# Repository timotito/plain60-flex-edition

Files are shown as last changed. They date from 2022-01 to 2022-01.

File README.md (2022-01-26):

# Plain60 Flex Edition rev2.2.1
This is an independently developed branch of the Plain60 Flex Edition, by evyd13.

Plain60 Flex Edition PCB
This universal 60% PCB is designed to support as little layouts as possible without limiting usability for most users. The reason evyd13 did this is because other PCBs made for this form factor usually have so many supported layouts that it could almost qualify as swiss cheese.

It also features a fuse and an ESD protection chip to protect the MCU and other parts of the PCB.

## Features
- Fits in the TGR Unikorn
- Compatible with QMK Firmware and VIA Configurator (if you flash a VIA compatible .hex file)
- Compatible with most universal 60% cases and HHKB/WKL Tofu by KBDfans
- USB type-C
- Optional JST header for connection with daughterboard
- Footprint for optional speaker (AST1109MLTRQ)
- ESD protection and fuse
- No LEDs and no underglow
- Minimal layout support
- ISP header

## Supported layouts
Supported layouts of the Plain60-C

## Building
If you feel like building a few of these PCBs yourself, the required gerber files are in the named folder. Order those at your favourite PCB manufacturer, get the components needed (see included BOM) and solder them on! Alternatively, request SMT assembly from the manufacturer.

A hot air station is not required but a soldering iron is. Flux is recommended.

## Opening the project
To open the files you will need KiCAD.

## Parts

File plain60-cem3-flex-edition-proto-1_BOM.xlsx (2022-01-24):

LCSC part # | Designator | Type | Value | Package | Amount | Description
C38141 (https://lcsc.com/product-detail/Multilayer-Ceramic-Capacitors-MLCC-SMD-SMT_FH-Guangdong-Fenghua-Advanced-Tech-0805B104K500NT_C38141.html) | 0.1u | Capacitor | 0.1uF | 0805 | 4 | 50V 100nF X7R ±10% 0805 Multilayer Ceramic Capacitors MLCC - SMD/SMT ROHS
C106843 (https://www.lcsc.com/product-detail/Multilayer-Ceramic-Capacitors-MLCC-SMD-SMT_YAGEO-CC0805KKX7R9BB474_C106843.html) | 4.7u | Capacitor | 4.7uF | 0805 | 1 | 50V 470nF X7R ±10% 0805 Multilayer Ceramic Capacitors MLCC - SMD/SMT ROHS
C215803 | 1u | Capacitor | 1uF | 0805 | 1 | 50V 1uF X7R ±10% 0805 Multilayer Ceramic Capacitors MLCC - SMD/SMT ROHS
C109001 | D1, D2, D3, D4, D5, D6, D7, D8, D9, D10, D11, D12, D13, D14, D15, D16, D17, D18, D19, D20, D21, D22, D23, D24, D25, D26, D27, D28, D29, D31, D32, D33, D34, D35, D36, D37, D38, D39, D40, D41, D42, D43, D44, D46, D47, D48, D49, D50, D51, D52, D53, D54, D55, D56, D57, D58, D59, D61, D62, D63, D67, D71, D72, D73, D74 | Diode |  | 0805 | 65 | 75V +150℃@(Tj) 400mW 1.25V@100mA 4ns 5μA@75V 150mA 0805 Switching Diode ROHS
C261942 | F1 | Fuse |  | 0805 | 1 | 6V 500mA 100A 500mW -40℃~+85℃ 1A 100ms 0805 Resettable Fuses ROHS
C165948 | J1 | Connector |  | HRO-TYPE-C-31-M-12 | 1 | 250mA 1 16 Female Type-C SMD USB Connectors ROHS
C103904 | 10k | Resistor | 10K | 0805 | 2 | ±1% 1/8W Thick Film Resistors 150V ±100ppm/℃ -55℃~+155℃ 10kΩ 0805 Chip Resistor - Surface Mount ROHS
C212411 | 5.1k | Resistor | 5.1K | 0805 | 2 | ±1% 1/8W Thick Film Resistors 150V ±100ppm/℃ -55℃~+155℃ 5.1kΩ 0805 Chip Resistor - Surface Mount ROHS
C325772 | 22 | Resistor | 22 | 0805 | 2 | ±1% 0.125W 22Ω 0805 Chip Resistor - Surface Mount ROHS
C44854 | U1 | MCU | 32U4 | QFP-44 | 1 | 16MHz AVR 2.7V ~ 5.5V QFP-44_10x10x08P ATMEL & AVR ROHS
C7519 | U2 | ESD chip |  | SOT23-6 | 1 | 17V 5A 5.25V 6V Unidirectional SOT-23-6 ESD Protection Devices ROHS
C341521 | X1 | Resonator | 16MHz | SMD | 1 | 16MHz ±0.5% 15pF 40Ω SMD3213-3P Ceramic Resonators ROHS
C92584 | SW1 | Switch |  | SMD | 1 | -25℃~+85℃ 5.2mm 1.5mm Round Button 50mA Brick nogging 5.2mm SPST 100MΩ 100000 250gf@±30gf 12V SMD Tactile Switches ROHS
C160404 | UDB | Optional JST |  | SMD | 1 | 1x4P 1 SR/SZ 1mm 4 Copper Alloy - Wire To Board / Wire To Wire Connector ROHS

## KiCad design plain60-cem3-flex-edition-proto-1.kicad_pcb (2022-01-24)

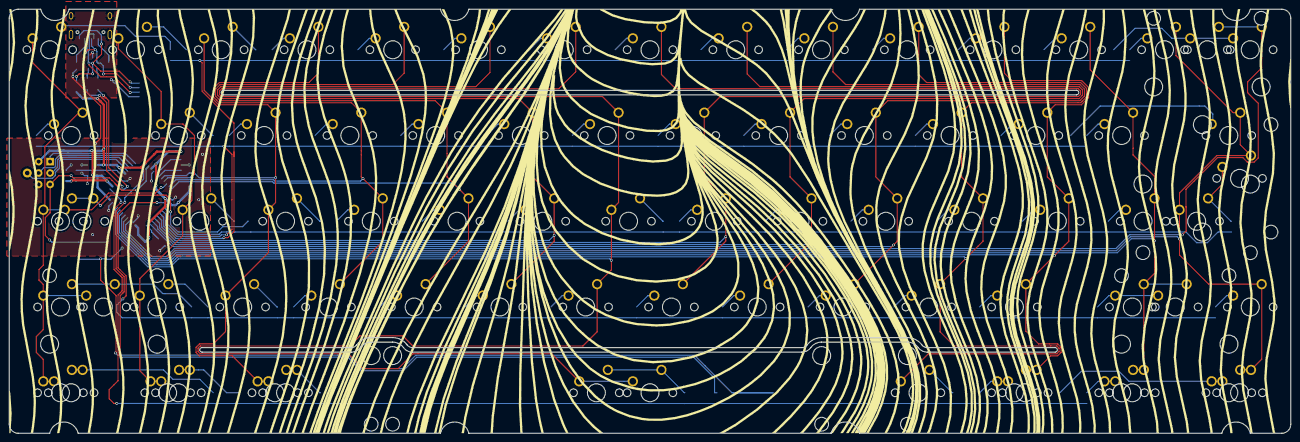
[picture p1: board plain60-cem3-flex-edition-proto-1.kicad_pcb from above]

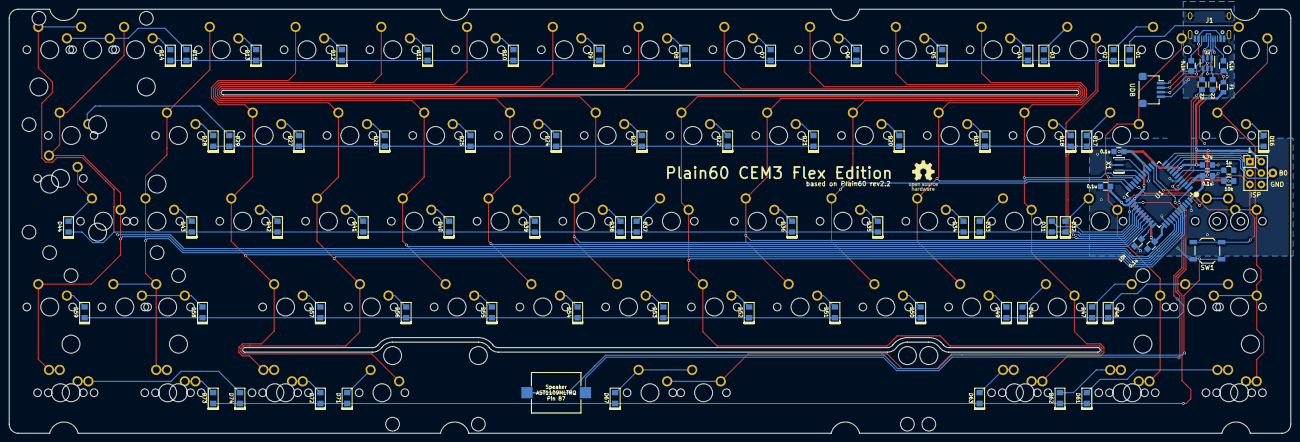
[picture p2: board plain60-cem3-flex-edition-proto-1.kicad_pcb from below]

Board: 2 copper layers, 284.7 x 94.2 mm, 174 parts (87 on the bottom side), 106 nets.

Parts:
C1: 1u; C_0805
C2, C3, C4, C5: 0.1u; C_0805
C6: 4.7u; C_0805
D1: D1; D_0805
D2: D2; D_0805
D3: D3; D_0805
D4: D4; D_0805
D5: D5; D_0805
D6: D6; D_0805
D7: D7; D_0805
D8: D8; D_0805
D9: D9; D_0805
D10: D10; D_0805
D11: D11; D_0805
D12: D12; D_0805
D13: D13; D_0805
D14: D14; D_0805
D15: D15; D_0805
D16: D16; D_0805
D17: D17; D_0805
D18: D18; D_0805
D19: D19; D_0805
D20: D20; D_0805
D21: D21; D_0805
D22: D22; D_0805
D23: D23; D_0805
D24: D24; D_0805
D25: D25; D_0805
D26: D26; D_0805
D27: D27; D_0805
D28: D28; D_0805
D29: D29; D_0805
D31: D31; D_0805
D32: D32; D_0805
D33: D33; D_0805
D34: D34; D_0805
D35: D35; D_0805
D36: D36; D_0805
D37: D37; D_0805
D38: D38; D_0805
D39: D39; D_0805
D40: D40; D_0805
D41: D41; D_0805
D42: D42; D_0805
D43: D43; D_0805
D44: D44; D_0805
D46: D46; D_0805
D47: D47; D_0805
D48: D48; D_0805
D49: D49; D_0805
D50: D50; D_0805
D51: D51; D_0805
D52: D52; D_0805
D53: D53; D_0805
D54: D54; D_0805
D55: D55; D_0805
D56: D56; D_0805
D57: D57; D_0805
D58: D58; D_0805
D59: D59; D_0805
D61: D61; D_0805
D62: D62; D_0805
D63: D63; D_0805
D67: D67; D_0805
D71: D71; D_0805
D72: D72; D_0805
D73: D73; D_0805
D74: D74; D_0805
F1: Polyfuse; R_0805
H1: B0; free_pin
J1: HRO-TYPE-C-31-M-12
J2: ISP; isp_standard
J3: ai03_ud; JST_SH_SM04B-SRSS-TB_1x04-1MP_P1.00mm_Horizontal
K1, K2, K3, K4, K5, K6, K7, K8, K9, K10, K11, K12, K13, K14, K15-1, K17, K18, K19, K20, K21, K22, K23, K24, K25, K26, K27, K28, K32, K33, K34, K35, K36, K37, K38, K39, K40, K41, K42, K43, K47, K48, K49, K50, K51, K52, K53, K54, K55, K56, K57, K59, K62-1, K73-1: KEYSW; CHERRY_PLATE_100H
K15: KEYSW; CHERRY_PCB_200H
K16, K29, K61-1, K63-1, K72-1, K74-1: KEYSW; CHERRY_PLATE_150H
K31, K58-1: KEYSW; CHERRY_PLATE_175H
K31-1, K46-1, K61, K62, K63, K71, K72, K73, K74: KEYSW; CHERRY_PLATE_125H
K44: KEYSW; CHERRY_PCB_225H_F
K44-1: KEYSW; CHERRY_PCB_200H_V
K46: KEYSW; CHERRY_PCB_225H
K58: KEYSW; CHERRY_PCB_275H
K67: KEYSW; CHERRY_PCB_625H_F
K67-1: KEYSW; CHERRY_PCB_700H_F
LS1: Speaker; speaker_AST1109MLTRQ
R1, R2: 22; R_0805
R3, R4: 5.1k; R_0805
R5, R6: 10k; R_0805
Ref**: Val**; redss
S1, S2, S3, S6: Screw; 5.5_5x2.5mm
S4, S5: Screw; 10x5_7x2.5mm
S7, S8, S9: Tofu screw; 5.5_5x2.5mm
SW1: SW_PUSH; SW_SPST_TL3342
U1: ATmega32U4; ATMEGA32U4
U2: USBLC6-2SC6
X1: XTAL_GND; Resonator_SMD_muRata_CSTNExxV-3Pin-p1.2

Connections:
D+: J1.6 (DP1), J1.8 (DP2), J3.3, U2.1 (I/O1)
D-: J1.5 (DN2), J1.7 (DN1), J3.2, U2.3 (I/O2)
GND: C1.2, C2.1, C3.1, C4.1, C5.1, C6.1, J1.1 (GND), J1.12 (GND), J1.13 (SHIELD), J2.6, J3.4, LS1.2, R3.1, R4.2, R6.1, SW1.1, U1.5 (UGND), U1.15 (GND), U1.23 (GND), U1.35 (GND), U1.43 (GND), U2.2 (GND), X1.3
MISO: J2.1, U1.11 ((PDO/MISO/PCINT3)PB3)
MOSI: J2.4, U1.10 ((PDI/MOSI/PCINT2)PB2)
unnamed: C1.1, U1.6 (UCAP)
unnamed: D1.2 (A), K1.1
unnamed: D2.2 (A), K2.1
unnamed: D3.2 (A), K3.1
unnamed: D4.2 (A), K4.2
unnamed: D5.2 (A), K5.2
unnamed: D6.2 (A), K6.2
unnamed: D7.2 (A), K7.2
unnamed: D8.2 (A), K8.2
unnamed: D9.2 (A), K9.2
unnamed: D10.2 (A), K10.2
unnamed: D11.2 (A), K11.2
unnamed: D12.2 (A), K12.2
unnamed: D13.2 (A), K13.2
unnamed: D14.2 (A), K14.2
unnamed: D15.2 (A), K15.2, K15-1.2
unnamed: D16.2 (A), K16.2
unnamed: D17.2 (A), K17.1
unnamed: D18.2 (A), K18.2
unnamed: D19.2 (A), K19.2
unnamed: D20.2 (A), K20.2
unnamed: D21.2 (A), K21.2
unnamed: D22.2 (A), K22.2
unnamed: D23.2 (A), K23.2
unnamed: D24.2 (A), K24.2
unnamed: D25.2 (A), K25.2
unnamed: D26.2 (A), K26.2
unnamed: D27.2 (A), K27.2
unnamed: D28.2 (A), K28.2
unnamed: D29.2 (A), K29.2
unnamed: D31.2 (A), K31.1, K31-1.1
unnamed: D32.2 (A), K32.1
unnamed: D33.2 (A), K33.1
unnamed: D34.2 (A), K34.2
unnamed: D35.2 (A), K35.2
unnamed: D36.2 (A), K36.2
unnamed: D37.2 (A), K37.1
unnamed: D38.2 (A), K38.2
unnamed: D39.2 (A), K39.2
unnamed: D40.2 (A), K40.2
unnamed: D41.2 (A), K41.2
unnamed: D42.2 (A), K42.2
unnamed: D43.2 (A), K43.2
unnamed: D44.2 (A), K44.1, K44-1.2
unnamed: D46.2 (A), K46.1, K46-1.1
unnamed: D47.2 (A), K47.1
unnamed: D48.2 (A), K48.1
unnamed: D49.2 (A), K49.2
unnamed: D50.2 (A), K50.2
unnamed: D51.2 (A), K51.2
unnamed: D52.2 (A), K52.2
unnamed: D53.2 (A), K53.2
unnamed: D54.2 (A), K54.2
unnamed: D55.2 (A), K55.2
unnamed: D56.2 (A), K56.2
unnamed: D57.2 (A), K57.2
unnamed: D58.2 (A), K58.2, K58-1.2
unnamed: D59.2 (A), K59.2
unnamed: D61.2 (A), K61.1, K61-1.1
unnamed: D62.2 (A), K62.1, K62-1.1
unnamed: D63.2 (A), K63.1, K63-1.1
unnamed: D67.2 (A), K67.1, K67-1.1
unnamed: D71.2 (A), K71.1
unnamed: D72.2 (A), K72.2, K72-1.2
unnamed: D73.2 (A), K73.2, K73-1.2
unnamed: D74.2 (A), K74.2, K74-1.2
unnamed: H1.1, U1.8 ((SS/PCINT0)PB0)
unnamed: J1.4 (CC1), R3.2
unnamed: J1.10 (CC2), R4.1
unnamed: LS1.1, U1.12 ((OC0A/OC1C/~RTS~/PCINT7)PB7)
unnamed: R1.1, U1.4 (D+)
unnamed: R1.2, U2.6 (I/O1)
unnamed: R2.1, U2.4 (I/O2)
unnamed: R2.2, U1.3 (D-)
unnamed: R6.2, U1.33 ((~HWB~)PE2)
unnamed: U1.16 (XTAL2), X1.2
unnamed: U1.17 (XTAL1), X1.1
RST: J2.5, R5.1, SW1.2, U1.13 (RESET)
SCK: J2.3, U1.9 ((SCLK/PCINT1)PB1)
VBUS: F1.2, J1.2 (VBUS), J1.11 (VBUS), J3.1, U2.5 (VBUS)
VCC: C2.2, C3.2, C4.2, C5.2, C6.2, F1.1, J2.2, R5.2, U1.2 (UVCC), U1.7 (VBUS), U1.14 (VCC), U1.24 (AVCC), U1.34 (VCC), U1.44 (AVCC)
col0: K1.2, K16.1, K31.2, K31-1.2, K46.2, K46-1.2, K61.2, K61-1.2, U1.20 ((RXD/INT2)PD2)
col1: K2.2, K17.2, K32.2, K47.2, K62.2, K62-1.2, U1.19 ((SDA/INT1)PD1)
col2: K3.2, K18.1, K33.2, K48.2, K63.2, K63-1.2, U1.18 ((OC0B/SCL/INT0)PD0)
col3: K4.1, K19.1, K34.1, K49.1, U1.21 ((TXD/INT3)PD3)
col4: K5.1, K20.1, K35.1, K50.1, U1.22 ((XCK1/~CTS~)PD5)
col5: K6.1, K21.1, K36.1, K51.1, U1.29 ((ADC12/OC1A/~OC4B~/PCINT12)PB5)
col6: K7.1, K22.1, K37.2, K52.1, K67.2, K67-1.2, U1.41 ((ADC0)PF0)
col7: K8.1, K23.1, K38.1, K53.1, U1.30 ((ADC13/OC1B/OC4B/PCINT13)PB6)
col8: K9.1, K24.1, K39.1, K54.1, U1.31 ((OC3A/~OC4A~)PC6)
col9: K10.1, K25.1, K40.1, K55.1, U1.32 ((ICP3/CLK0/OC4A)PC7)
col10: K11.1, K26.1, K41.1, K56.1, K71.2, U1.40 ((ADC1)PF1)
col11: K12.1, K27.1, K42.1, K57.1, K72.1, K72-1.1, U1.39 ((ADC4/TCK)PF4)
col12: K13.1, K28.1, K43.1, K58.1, K58-1.1, K73.1, K73-1.1, U1.38 ((ADC5/TMS)PF5)
col13: K14.1, K29.1, K44.2, K44-1.1, K59.1, K74.1, K74-1.1, U1.37 ((ADC6/TDO)PF6)
col14: K15.1, K15-1.1, U1.36 ((ADC7/TDI)PF7)
row0: D1.1 (K), D2.1 (K), D3.1 (K), D4.1 (K), D5.1 (K), D6.1 (K), D7.1 (K), D8.1 (K), D9.1 (K), D10.1 (K), D11.1 (K), D12.1 (K), D13.1 (K), D14.1 (K), D15.1 (K), U1.28 ((ADC11/PCINT4)PB4)
row1: D16.1 (K), D17.1 (K), D18.1 (K), D19.1 (K), D20.1 (K), D21.1 (K), D22.1 (K), D23.1 (K), D24.1 (K), D25.1 (K), D26.1 (K), D27.1 (K), D28.1 (K), D29.1 (K), U1.27 ((T0/OC4D/ADC10)PD7)
row2: D31.1 (K), D32.1 (K), D33.1 (K), D34.1 (K), D35.1 (K), D36.1 (K), D37.1 (K), D38.1 (K), D39.1 (K), D40.1 (K), D41.1 (K), D42.1 (K), D43.1 (K), D44.1 (K), U1.26 ((T1/~OC4D~/ADC9)PD6)
row3: D46.1 (K), D47.1 (K), D48.1 (K), D49.1 (K), D50.1 (K), D51.1 (K), D52.1 (K), D53.1 (K), D54.1 (K), D55.1 (K), D56.1 (K), D57.1 (K), D58.1 (K), D59.1 (K), U1.25 ((ICP2/ADC8)PD4)
row4: D61.1 (K), D62.1 (K), D63.1 (K), D67.1 (K), D71.1 (K), D72.1 (K), D73.1 (K), D74.1 (K), U1.1 ((INT6/AIN0)PE6)
